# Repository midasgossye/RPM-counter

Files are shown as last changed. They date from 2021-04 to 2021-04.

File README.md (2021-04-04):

# RPM counter



## Repo structure

* [**Electronics:**](https://github.com/midasgossye/RPM-counter/tree/main/Electronics) Contains everything related to the Electronics, this includes the schematic (in pdf), KiCad files (schematic & PCB layout), PCB gerber files and a BOM (Bill Of Materials)
* [**Programming:**](https://github.com/midasgossye/RPM-counter/tree/main/Programming) Contains the Arduino source code
* [**CAD:**](https://github.com/midasgossye/RPM-counter/tree/main/CAD) Contains the 3D design files (Solidworks & STEP format) and STL files for 3D printing of the case
* [**images:**](https://github.com/midasgossye/RPM-counter/tree/main/images) Images of RPM counter

## Acknowledgements:

This project is mainly based on GreatScott's DIY RPM meter. Check out his awesome video where he explains the design process and working details of his DIY RPM meter/tachometer based on a cheap IR distance sensor module: [youtu.be/6QZMt4yyylU](https://youtu.be/6QZMt4yyylU)

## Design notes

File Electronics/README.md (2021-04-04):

# RPM counter Electronics

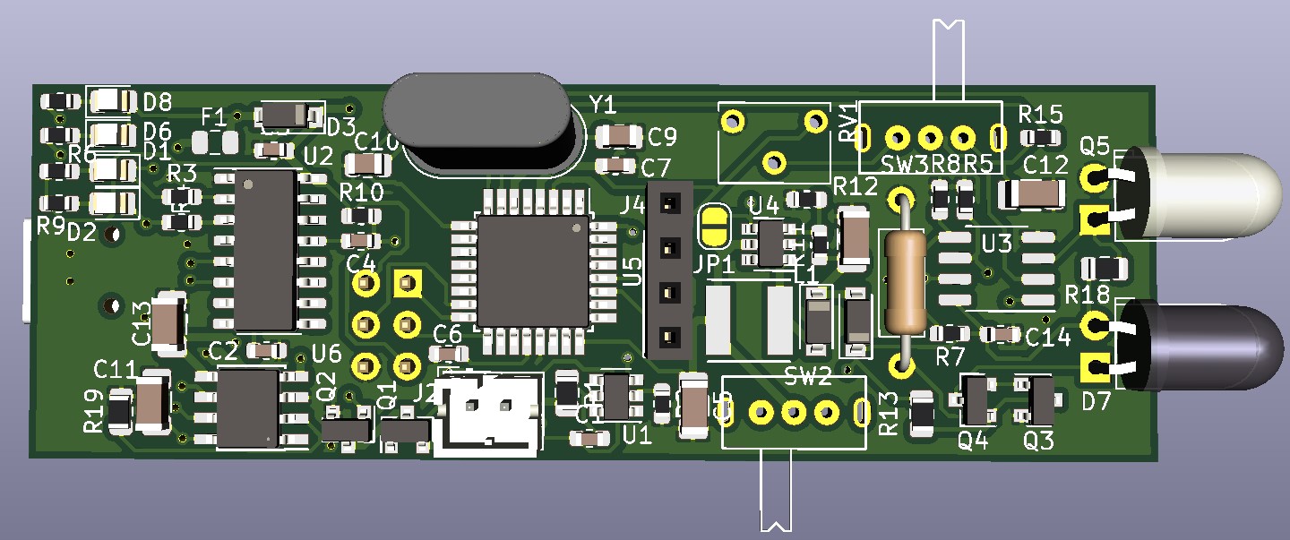
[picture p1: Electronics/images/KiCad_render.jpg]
PCB render KiCad


This folder contains the schematic, BOM, KiCad files and gerber fabrication files for the PCB.

## Main features:

* ATMEGA328P Microcontroller with Arduino bootloader
* Built-in CH340 based USB <-> Serial
* Constant current IR LED driver
* Runs on single-cell LiPo
  * TP4560 based LiPo battery charger
  * LiPo protection circuitry
  * 3.3 V -> 5 V boost converter

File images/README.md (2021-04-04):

# RPM counter Images

## Front side


## LED side


## Insides


## Measuring RPM of fan


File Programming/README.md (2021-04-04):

# RPM counter Programming

The Arduino sketch is largely based on GreatScott's program from his easy DIY tachometer project. See his instructable page for details: [www.instructables.com/DIY-Tachometer-RPM-Meter/](https://www.instructables.com/DIY-Tachometer-RPM-Meter/)

## Library dependencies:

* u8x8, part of [u8g2 library](https://github.com/olikraus/u8g2)

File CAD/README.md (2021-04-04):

# RPM counter CAD

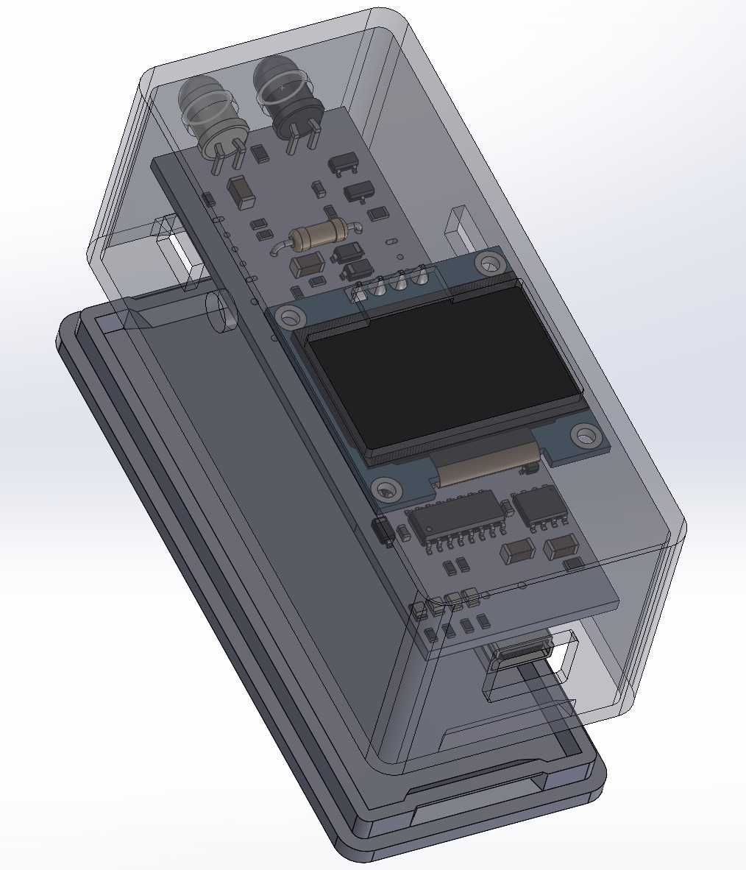
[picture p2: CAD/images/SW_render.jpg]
SW render


The case design for this project was based on Adafruits fantastic [Snap-fit case design Fusion360 tutorial](https://youtu.be/VVmOtM60VWw).

The design employs a snap-fit case with holes for the LEDs, OLED screen, switches, USB connector and room for the LiPo battery.

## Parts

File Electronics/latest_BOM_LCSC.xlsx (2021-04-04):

Item | Qty | Reference(s) | Value | LibPart | Footprint | MFR PART#
1 | 7 | C1, C2, C3, C4, C6, C7, C14 | 100n | Device:C_Small | Capacitor_SMD:C_0603_1608Metric | 0603B104M250
2 | 5 | C5, C8, C11, C12, C13 | 22u | Device:CP | Capacitor_SMD:C_1206_3216Metric | CL31A226KOHNNNE
3 | 2 | C9, C10 | 22p | Device:C_Small | Capacitor_SMD:C_0805_2012Metric
4 | 1 | D1 | Rx | Device:LED | LED_SMD:LED_0805_2012Metric
5 | 1 | D2 | Tx | Device:LED | LED_SMD:LED_0805_2012Metric
6 | 3 | D3, D4, D5 | SS24FL | Device:D_Schottky | Diode_SMD:D_SOD-123 | SS24FL
7 | 1 | D6 | Green | Device:LED | LED_SMD:LED_0805_2012Metric
8 | 1 | D7 | DY-IR333-A | Device:LED | LED_THT:LED_D5.0mm_Horizontal_O1.27mm_Z3.0mm_IRGrey | DY-IR333-A
9 | 1 | D8 | Red | Device:LED | LED_SMD:LED_0805_2012Metric
10 | 1 | F1 | 500 mA | Device:Polyfuse | Fuse:Fuse_0805_2012Metric | JK-SMD0805-020
11 | 1 | J1 | USB_B_Mini | Connector:USB_B_Mini | SMD_connectors:C105424 | C105424
12 | 1 | J2 | LiPo | Connector_Generic:Conn_01x02 | Connector_JST:JST_PH_B2B-PH-K_1x02_P2.00mm_Vertical
13 | 1 | J3 | AVR-ISP-6 | Connector:AVR-ISP-6 | Connector_PinHeader_2.54mm:PinHeader_2x03_P2.54mm_Vertical | 210-92-03GB01
14 | 1 | J4 | OLED | Connector_Generic:Conn_01x04 | Connector_PinSocket_2.54mm:PinSocket_1x04_P2.54mm_Vertical
15 | 1 | JP1 | Force_boost | Jumper:SolderJumper_2_Open | Jumper:SolderJumper-2_P1.3mm_Open_RoundedPad1.0x1.5mm
16 | 1 | JP2 | Auto Boost Shutoff | Jumper:SolderJumper_2_Open | Jumper:SolderJumper-2_P1.3mm_Open_RoundedPad1.0x1.5mm
17 | 1 | L1 | 22u | Device:L | SMD_inductors:SNR5040K-SERIES | SNR5040K-220M
18 | 2 | Q1, Q2 | SL2302S | Device:Q_NMOS_GSD | Package_TO_SOT_SMD:SOT-23 | SL2302S
19 | 2 | Q3, Q4 | PMBT3904 | Device:Q_NPN_BEC | Package_TO_SOT_SMD:SOT-23 | PMBT3904,215
20 | 1 | Q5 | DY-PT333-6C | Device:Q_Photo_NPN_CE | LED_THT:LED_D5.0mm_Horizontal_O1.27mm_Z3.0mm_Clear | DY-PT333-6C
21 | 1 | R1 | 100 | Device:R_Small | Resistor_SMD:R_0805_2012Metric
22 | 6 | R2, R3, R4, R6, R9, R15 | 1k | Device:R | Resistor_SMD:R_0603_1608Metric | 0603WAF1001T5E
23 | 3 | R5, R7, R8 | 10k | Device:R | Resistor_SMD:R_0603_1608Metric
24 | 1 | R10 | 10k | Device:R_Small | Resistor_SMD:R_0603_1608Metric
25 | 1 | R11 | 36k | Device:R | Resistor_SMD:R_0603_1608Metric
26 | 1 | R12 | 4.7k | Device:R | Resistor_SMD:R_0603_1608Metric
27 | 1 | R13 | 2k2 | Device:R | Resistor_SMD:R_0805_2012Metric
28 | 1 | R14 | 39R | Device:R | Resistor_THT:R_Axial_DIN0207_L6.3mm_D2.5mm_P10.16mm_Horizontal | MFR0W4F390JA50
29 | 2 | R16, R17 | 1k | Device:R_Small | Resistor_SMD:R_0603_1608Metric | 0603WAF1001T5E
30 | 2 | R18, R19 | R | Device:R | Resistor_SMD:R_0805_2012Metric
31 | 1 | RV1 | 10k | Device:R_POT | Potentiometer_THT:Potentiometer_Vishay_T73XX_Horizontal | 3362S-1-103
32 | 2 | SW2, SW3 | SPDT | Switch:SW_SPDT | SMD_switches:SK12D07VG5 | SK12D07VG5
33 | 1 | U1 | FS312F-G | Battery_charger:FS312F-G | Package_TO_SOT_SMD:SOT-23-6 | FS312F-G
34 | 1 | U2 | CH340C | Interface_USB:CH340G | Package_SO:SOIC-16_3.9x9.9mm_P1.27mm | CH340C
35 | 1 | U3 | LM393 | Comparator:LM393 | Package_SO:SOP-8_3.76x4.96mm_P1.27mm | LM393
36 | 1 | U4 | MT3608 | Boost_converter:MT3608 | Package_TO_SOT_SMD:SOT-23-6 | MT3608
37 | 1 | U5 | ATmega328P-AU | MCU_Microchip_ATmega:ATmega328P-AU | Package_QFP:TQFP-32_7x7mm_P0.8mm | ATMEGA328P-AU
38 | 1 | U6 | TP4056 | Battery_charger:TP4056 | Package_SO:TI_SO-PowerPAD-8_ThermalVias | TP4056
39 | 1 | Y1 | 16 MHz | Device:Crystal | Crystal:Crystal_HC18-U_Vertical | X49SD16MSD2SC

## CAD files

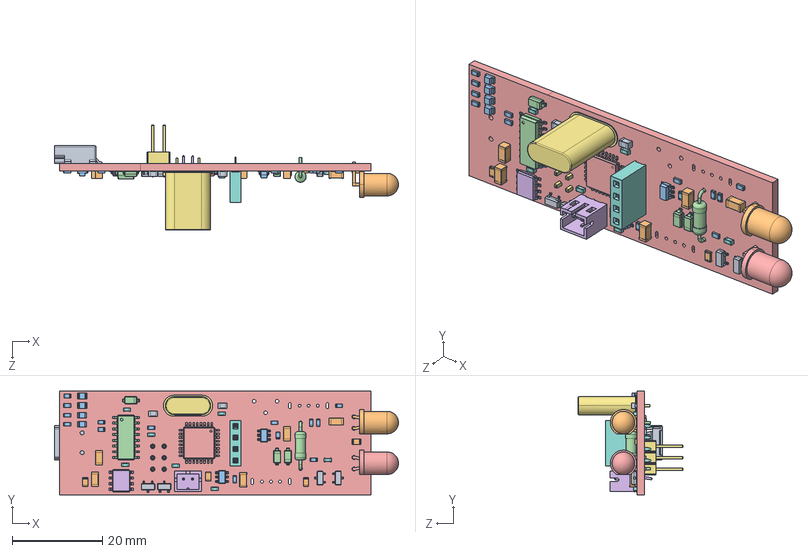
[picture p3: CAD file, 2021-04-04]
CAD/RPM_PCB.SLDASM
76.1 x 23.0 x 23.3 mm
SOLID.step
SOLID-0.step x 5
SOLID-1.step x 4
SOLID-2.step x 3
SOLID-3.step
SOLID-4.step
SOLID-5.step
SOLID-6.step
SOLID-7.step x 4
SOLID-8.step
SOLID-9.step x 2
SOLID-10.step
SOLID-11.step
SOLID-12.step
SOLID-13.step
SOLID-14.step x 7
SOLID-15.step x 2
SOLID-16.step x 4
SOLID-17.step x 14
SOLID-18.step
COMPOUND.step

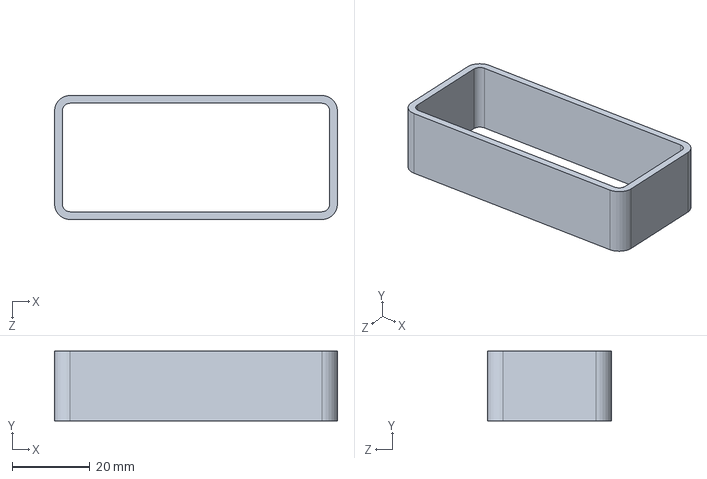
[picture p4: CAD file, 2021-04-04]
CAD/main.SLDPRT
73.0 x 18.0 x 32.0 mm

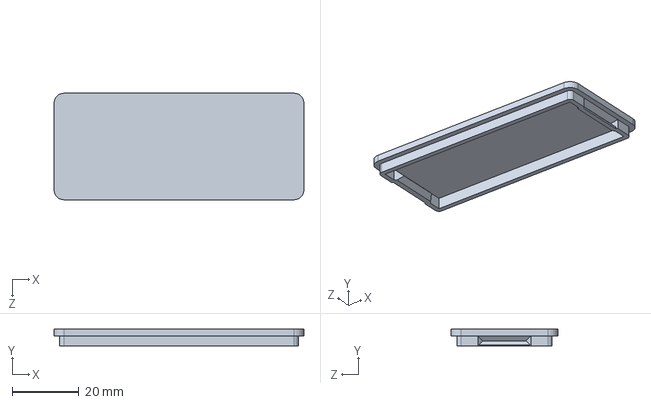
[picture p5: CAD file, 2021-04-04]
CAD/lid.SLDPRT
75.0 x 5.00 x 32.0 mm

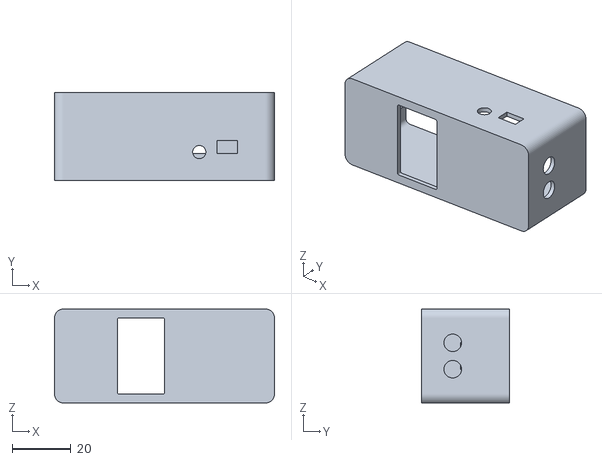
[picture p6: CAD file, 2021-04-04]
CAD/STLs/new_param_housing.STL
75.0 x 30.0 x 32.0

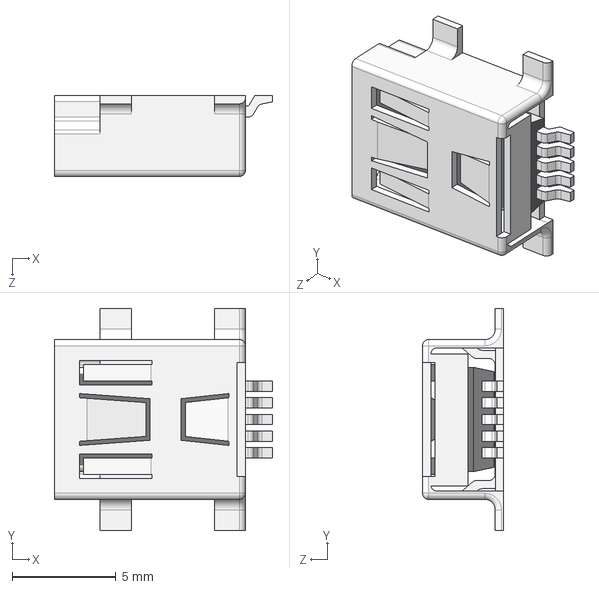
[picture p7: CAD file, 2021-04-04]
Electronics/KiCad_files/STEPs/Mini USB.STEP
10.5 x 10.7 x 3.90 mm

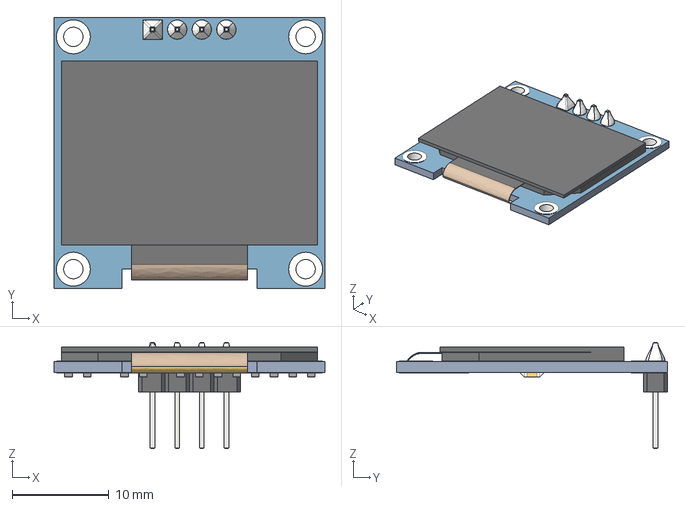
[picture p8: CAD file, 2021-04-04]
CAD/0.96 OLED v3.step
28.0 x 28.0 x 11.0 mm

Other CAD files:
CAD/param_housing.SLDPRT
CAD/STLs/lid.STL

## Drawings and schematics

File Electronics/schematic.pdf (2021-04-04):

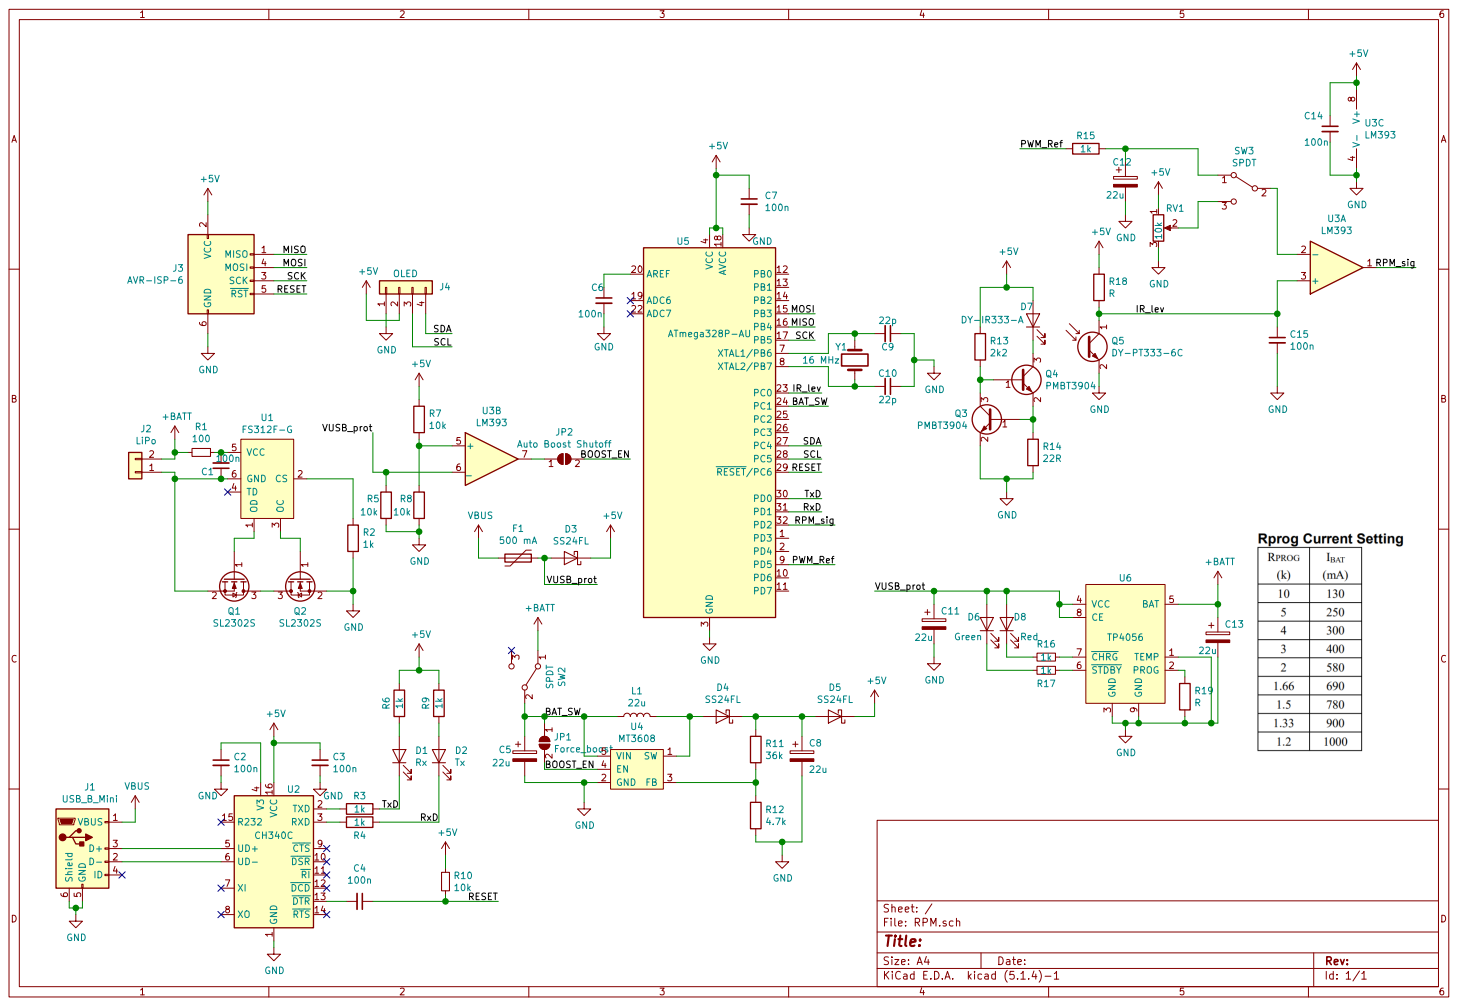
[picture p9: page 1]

2 SCK 3 MOSI 4 RST 5 GND

4 UD+ 5 UD- 6 XI 7 XO 8 CTS 9 U2 CH340C GND
D5 SS24FL GND

3 VCC 4 BAT 5 STDBY 6 CHRG 7 CE 8 GND

1 DSR 10 RI 11 DCD 12 DTR 13 RTS 14 R232 15 VCC 16 TXD 2 RXD 3 V3

Id: 1/1 Title: File: RPM.sch Sheet: /

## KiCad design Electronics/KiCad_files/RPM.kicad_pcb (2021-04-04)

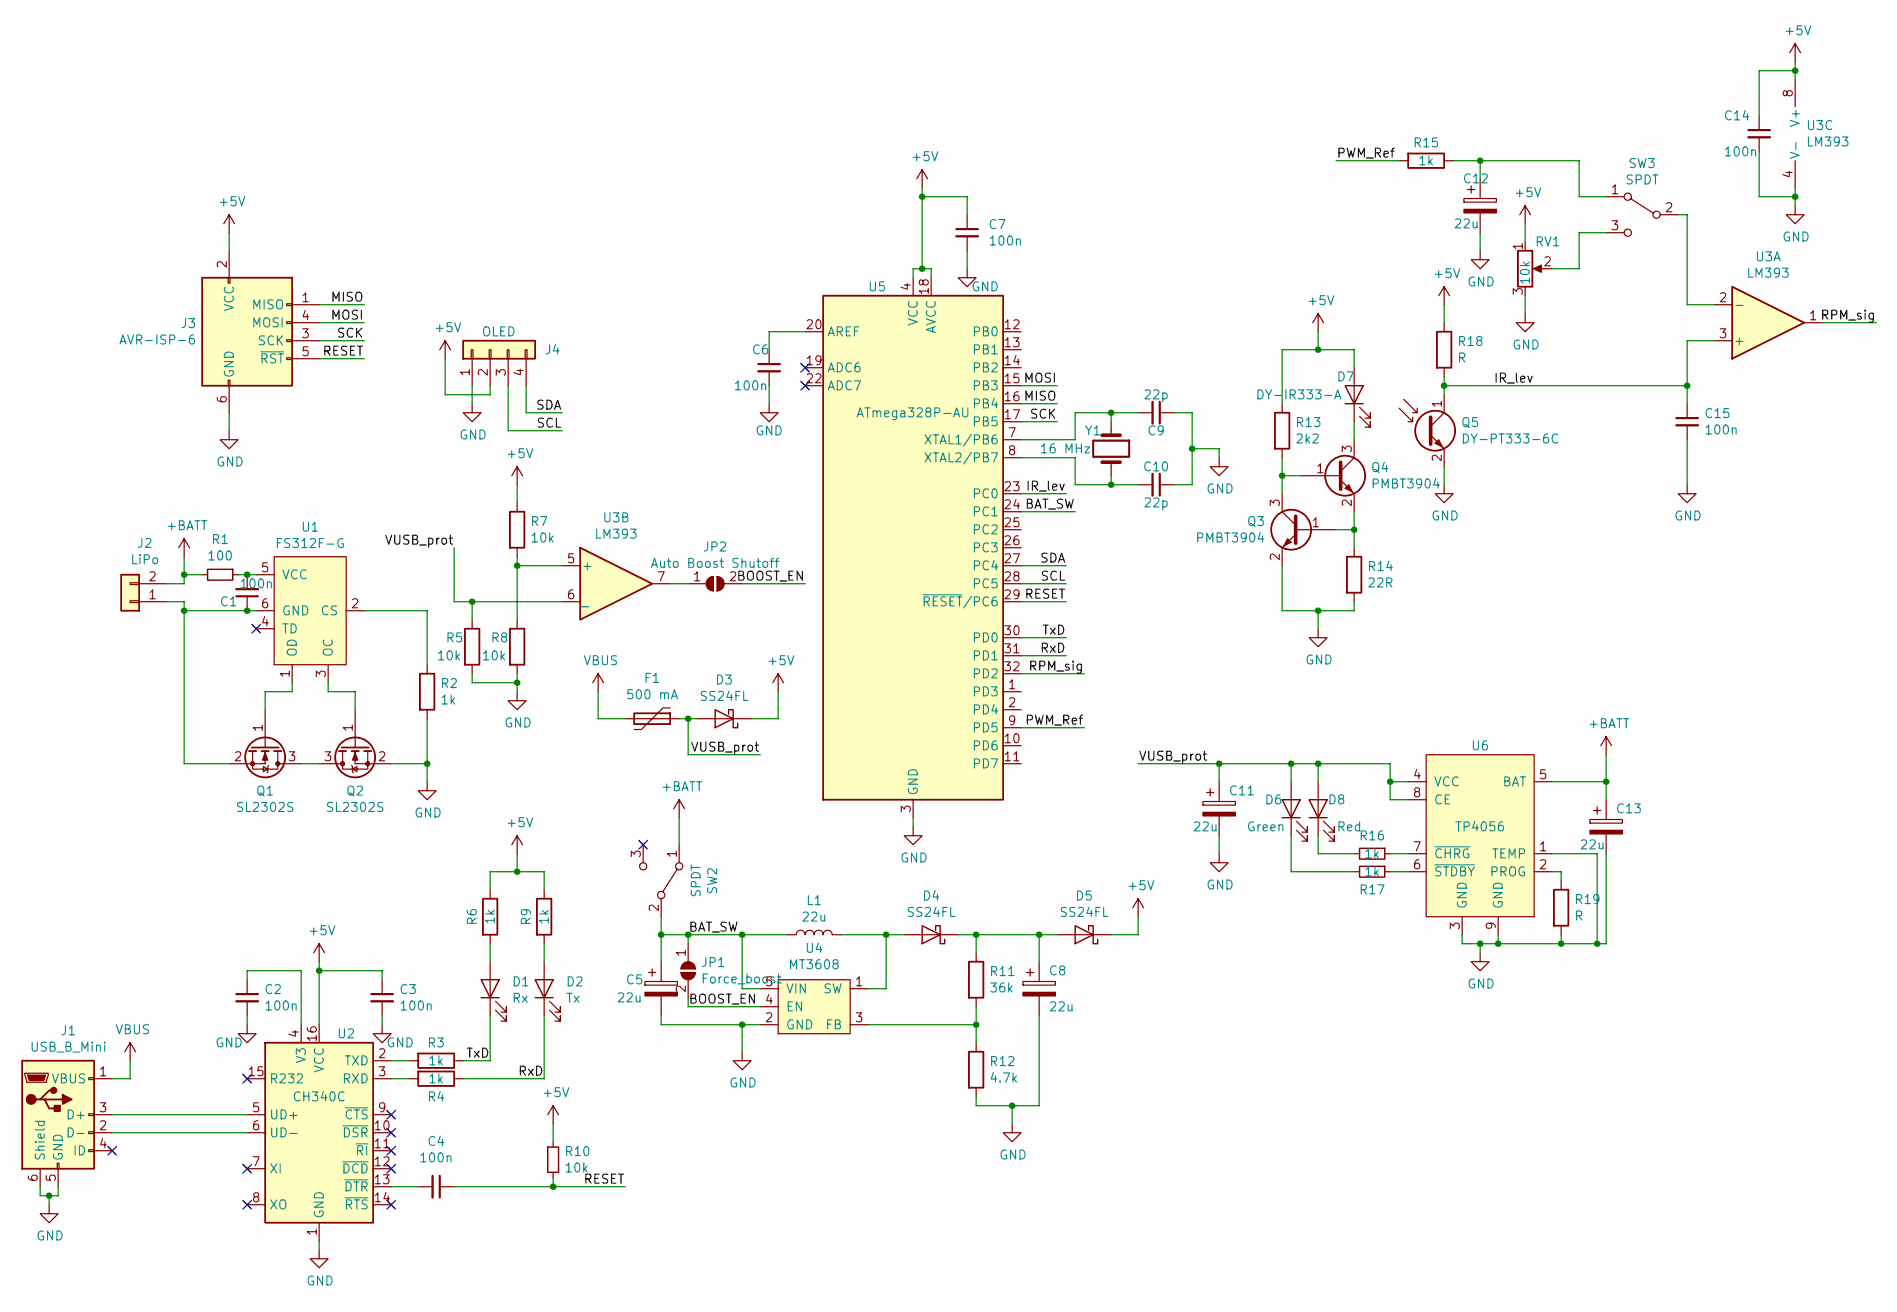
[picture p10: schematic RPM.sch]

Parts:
C1, C2, C3, C4, C6, C7, C14, C15: 100n; C_0603_1608Metric; MFR PART# 0603B104M250
C5, C8, C11, C12, C13: 22u; C_1206_3216Metric; MFR PART# CL31A226KOHNNNE
C9, C10: 22p; C_0805_2012Metric
D1: Rx; LED_0805_2012Metric
D2: Tx; LED_0805_2012Metric
D3, D4, D5: SS24FL; D_SOD-123; MFR PART# SS24FL
D6: Green; LED_0805_2012Metric
D7: DY-IR333-A; LED_D5.0mm_Horizontal_O1.27mm_Z3.0mm_IRGrey; MFR PART# DY-IR333-A
D8: Red; LED_0805_2012Metric
F1: 500 mA; Fuse_0805_2012Metric; MFR PART# JK-SMD0805-020
J1: USB_B_Mini; C105424; MFR PART# C105424
J2: LiPo; JST_PH_B2B-PH-K_1x02_P2.00mm_Vertical
J3: AVR-ISP-6; PinHeader_2x03_P2.54mm_Vertical; MFR PART# 210-92-03GB01
J4: OLED; PinSocket_1x04_P2.54mm_Vertical
JP1: Force_boost; SolderJumper-2_P1.3mm_Open_RoundedPad1.0x1.5mm
JP2: Auto Boost Shutoff; SolderJumper-2_P1.3mm_Open_RoundedPad1.0x1.5mm
L1: 22u; SNR5040K-SERIES; MFR PART# SNR5040K-220M
Q1, Q2: SL2302S; SOT-23; MFR PART# SL2302S
Q3, Q4: PMBT3904; SOT-23; MFR PART# PMBT3904,215
Q5: DY-PT333-6C; LED_D5.0mm_Horizontal_O1.27mm_Z3.0mm_Clear; MFR PART# DY-PT333-6C
R1: 100; R_0805_2012Metric
R2, R3, R4, R6, R9, R15, R16, R17: 1k; R_0603_1608Metric; MFR PART# 0603WAF1001T5E
R5, R7, R8, R10: 10k; R_0603_1608Metric; MFR PART# RTT03103JTP
R11: 36k; R_0603_1608Metric
R12: 4.7k; R_0603_1608Metric
R13: 2k2; R_0805_2012Metric
R14: 22R; R_Axial_DIN0207_L6.3mm_D2.5mm_P10.16mm_Horizontal; MFR PART# MFR0W4F390JA50
R18, R19: R; R_0805_2012Metric
RV1: 10k; Potentiometer_Vishay_T73XX_Horizontal; MFR PART# 3362S-1-103
SW2, SW3: SPDT; SK12D07VG5; MFR PART# SK12D07VG5
U1: FS312F-G; SOT-23-6; MFR PART# FS312F-G
U2: CH340C; SOIC-16_3.9x9.9mm_P1.27mm; MFR PART# CH340C
U3: LM393; SOP-8_3.76x4.96mm_P1.27mm; MFR PART# LM393
U4: MT3608; SOT-23-6; MFR PART# MT3608
U5: ATmega328P-AU; TQFP-32_7x7mm_P0.8mm; MFR PART# ATMEGA328P-AU
U6: TP4056; TI_SO-PowerPAD-8_ThermalVias; MFR PART# TP4056
Y1: 16 MHz; Crystal_HC18-U_Vertical; MFR PART# X49SD16MSD2SC

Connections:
+5V: C3.1, C7.1, C14.1, D3.1 (K), D5.1 (K), D7.2 (A), J3.2 (VCC), J4.2, R6.1, R7.1, R9.1, R10.1, R13.1, R18.1, RV1.1, U2.16 (VCC), U3.8 (V+), U5.4 (VCC), U5.6 (VCC), U5.18 (AVCC)
+BATT: C13.1, J2.2, R1.2, SW2.1 (A), U6.5 (BAT)
/BAT_SW: C5.1, JP1.1 (A), L1.1, SW2.2 (B), U4.5 (VIN), U5.24 (PC1)
/BOOST_EN: JP1.2 (B), JP2.2 (B), U4.4 (EN)
/IR_lev: C15.1, Q5.1 (C), R18.2, U3.3 (+), U5.23 (PC0)
/MISO: J3.1 (MISO), U5.16 (PB4)
/MOSI: J3.4 (MOSI), U5.15 (PB3)
/PWM_Ref: R15.2, U5.9 (PD5)
/RESET: C4.1, J3.5 (~RST), R10.2, U5.29 (~RESET~/PC6)
/RPM_sig: U3.1, U5.32 (PD2)
/RxD: D2.1 (K), R4.1, U5.31 (PD1)
/SCK: J3.3 (SCK), U5.17 (PB5)
/SCL: J4.3, U5.28 (PC5)
/SDA: J4.4, U5.27 (PC4)
/TxD: D1.1 (K), R3.1, U5.30 (PD0)
/VUSB_prot: C11.1, D3.2 (A), D6.2 (A), D8.2 (A), F1.1, R5.1, U3.6 (_), U6.4 (VCC), U6.8 (CE)
GND: C2.2, C3.2, C5.2, C6.2, C7.2, C8.2, C9.1, C10.1, C11.2, C12.2, C13.2, C14.2, C15.2, J1.5 (GND), J1.6 (Shield), J3.6 (GND), J4.1, Q2.2 (S), Q3.2 (E), Q5.2 (E), R2.2, R5.2, R8.2, R12.2, R14.2, R19.2, RV1.3, U2.1 (GND), U3.4 (V-), U4.2 (GND), U5.3 (GND), U5.5 (GND), U5.21 (GND), U6.1 (TEMP), U6.3 (GND), U6.9 (GND)
unnamed: C1.1, J2.1, Q1.2 (S), U1.6 (GND)
unnamed: C1.2, R1.1, U1.5 (VCC)
unnamed: C2.1, U2.4 (V3)
unnamed: C4.2, U2.13 (~DTR)
unnamed: C6.1, U5.20 (AREF)
unnamed: C8.1, D4.1 (K), D5.2 (A), R11.1
unnamed: C9.2, U5.7 (XTAL1/PB6), Y1.1
unnamed: C10.2, U5.8 (XTAL2/PB7), Y1.2
unnamed: C12.1, R15.1, SW3.1 (A)
unnamed: D1.2 (A), R6.2
unnamed: D2.2 (A), R9.2
unnamed: D4.2 (A), L1.2, U4.1 (SW)
unnamed: D6.1 (K), R17.2
unnamed: D7.1 (K), Q4.3 (C)
unnamed: D8.1 (K), R16.2
unnamed: J1.2 (D-), U2.6 (UD-)
unnamed: J1.3 (D+), U2.5 (UD+)
unnamed: JP2.1 (A), U3.7
unnamed: Q1.1 (G), U1.1 (OD)
unnamed: Q1.3 (D), Q2.3 (D)
unnamed: Q2.1 (G), U1.3 (OC)
unnamed: Q3.1 (B), Q4.2 (E), R14.1
unnamed: Q3.3 (C), Q4.1 (B), R13.2
unnamed: R2.1, U1.2 (CS)
unnamed: R3.2, U2.2 (TXD)
unnamed: R4.2, U2.3 (RXD)
unnamed: R7.2, R8.1, U3.5 (+)
unnamed: R11.2, R12.1, U4.3 (FB)
unnamed: R16.1, U6.7 (~CHRG)
unnamed: R17.1, U6.6 (~STDBY)
unnamed: R19.1, U6.2 (PROG)
unnamed: RV1.2, SW3.3 (C)
unnamed: SW3.2 (B), U3.2 (-)
VBUS: F1.2, J1.1 (VBUS)

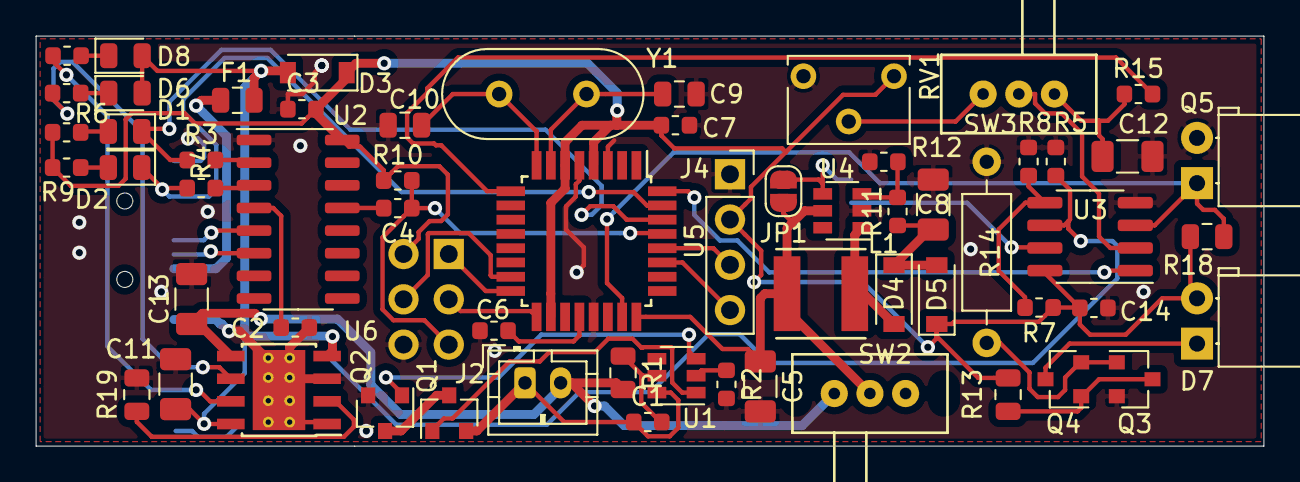
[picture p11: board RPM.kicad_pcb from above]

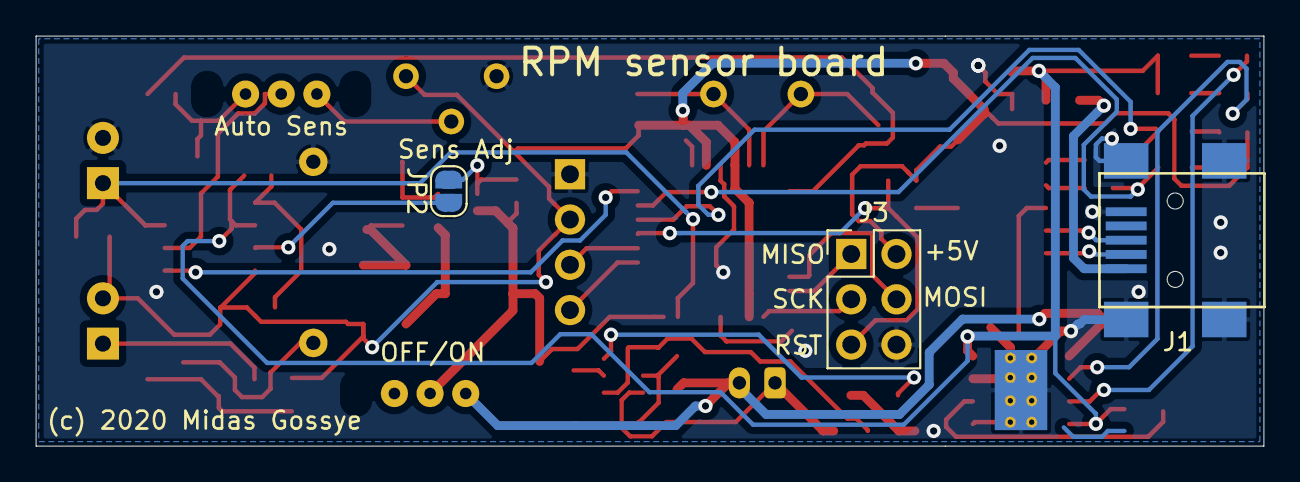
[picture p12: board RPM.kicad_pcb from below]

Board: 2 copper layers, 68.9 x 23.0 mm, 64 parts (3 on the bottom side), 51 nets.

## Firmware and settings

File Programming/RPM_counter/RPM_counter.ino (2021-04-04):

// Based on GreatScott's DIY tachometer
// URL: https://www.instructables.com/DIY-Tachometer-RPM-Meter/
// YT:  https://youtu.be/6QZMt4yyylU

#include <Arduino.h>
#include <U8x8lib.h>
#include <SPI.h>
#include <Wire.h>
U8X8_SSD1306_128X64_NONAME_HW_I2C u8x8(/* reset=*/ U8X8_PIN_NONE);
unsigned long rpmtime;
float rpmfloat;
unsigned int rpm;
bool tooslow = 1;
int dummy = 0;
void setup() {
  u8x8.begin();
  u8x8.setFont(u8x8_font_profont29_2x3_f);
  TCCR1A = 0;
  TCCR1B = 0;
  TCCR1B |= (1 << CS12); //Prescaler 256
  TIMSK1 |= (1 << TOIE1); //enable timer overflow
  pinMode(2, INPUT);

  attachInterrupt(0, RPM, FALLING);
}

ISR(TIMER1_OVF_vect) {
  tooslow = 1;
}


void loop() {
  
  delay(1000);
  if (tooslow == 1) {
    u8x8.clear();
    u8x8.drawString(1, 0, "SLOW!");
  }
  else {
    rpmfloat = 120 / (rpmtime/ 31250.00);
    rpm = round(rpmfloat);
    u8x8.clear();
    u8x8.setCursor(1,0);
    u8x8.print(rpm);
  }
}

void RPM () {
  rpmtime = TCNT1;
  TCNT1 = 0;
  tooslow = 0;
  
}

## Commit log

2021-04-04 added PCB design files
    [Mini USB.STEP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]
2021-04-04 added CAD
    [0.96 OLED v3.step, RPM_PCB.SLDASM, lid.SLDPRT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]
2021-04-04 Added CAD README
2021-04-04 Added Arduino code

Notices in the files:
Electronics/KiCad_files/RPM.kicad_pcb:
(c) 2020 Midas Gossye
